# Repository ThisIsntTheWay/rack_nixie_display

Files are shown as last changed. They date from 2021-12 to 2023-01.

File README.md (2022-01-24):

# Project overview
1U rack mounted nixie display with IN-4 and INS-1 tubes.  
Uses an ESP32 and, optionally, a temperature sensor (such as the TMP36).  

## Description
The display, on its own, cannot actually do anything.  
It is designed to be used in tandem with its extensive REST API that allows complete control over the display:
* Controlling each individual tube (IN-4 & INS-1).
  * Both digits and brightness.
* Controlling the tube LEDs (red) *(not individually, as of PCB REV1)*.
* Controlling the onboard LED (blue).
* Basic authentication mechanism to ensure only select devices can talk to the display.
 
### Preview
Here is REV1 of a fully assembled unit mounted in a rack.  


### Hardware
This project uses the following components:
* 6x `TLP627`
* 4x `IN-4`
* 4x `SN74141 (or clones)`
* 2x `INS-1`
* 1x `TMP36`
* 1x `ESP32`
* 1x `LDO 3.3V regulator`

*Exclusively SMD components are used where applicable.  
HV devices/traces use THT instead, as clearances and creepage distances would be violated otherwise.*

#### Power
The device runs on 5V **max** and gets fed using an onboard micro-USB socket.  
Additionally, it can be *fully* turned off using a dedicated slide switch.

The 170V regulator has been sourced externally and is not included in the component list.  
Virtually any regulator works, as long as it has similar dimensions to the popular `NCH8200HV`.

#### Notes
To save on vertical space (to stay within the 1U mounting constraint), the BCD-Decoders and opto-isolators reside on *extension boards*.  
These are connected using standard 2.54mm headers.  

It is recommended to mount them using *straight* 2.54mm headers, just to reduce the risk of accidential shocks.

#### Documentation
Please refer to the [wiki](https://github.com/ThisIsntTheWay/rack_nixie_display/wiki) for documentation.

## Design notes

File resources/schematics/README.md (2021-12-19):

# Schematics
This is the cozy, comfy folder for all my schematics.

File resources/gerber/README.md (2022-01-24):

# Gerber repository
This is where all the gerber files reside.

### Main board, rev 1
  

### Main board, rev 2
  
* Increased IN-4 hole diameter (to ~5.5mm).
* Added INS-1 mounting holes.
* Added left-hand rackmount adapter mounting holes. 
---

### Extension board, rev 1


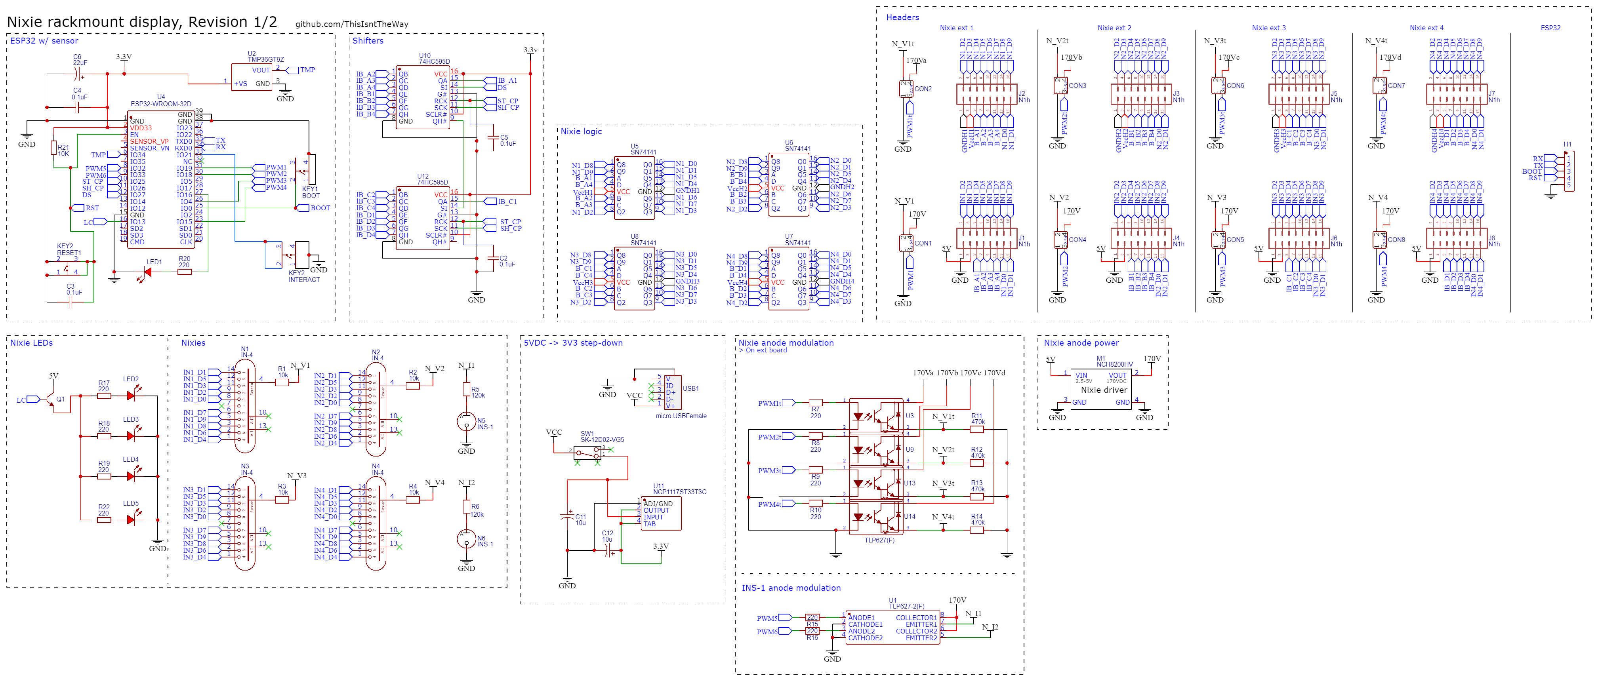
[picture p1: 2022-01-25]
resources/schematics/Schematic_rack_nixie_display_REV1-2.png

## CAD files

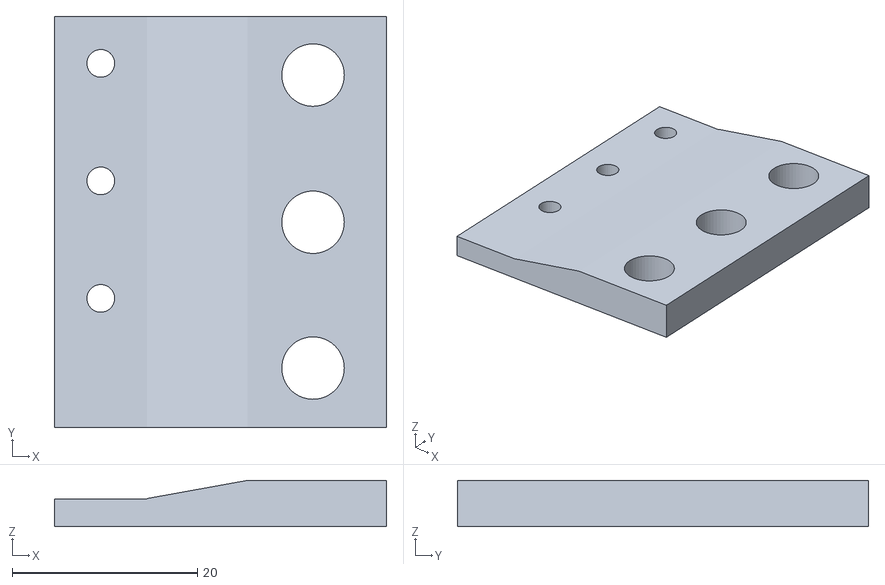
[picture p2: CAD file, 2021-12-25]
resources/3d_print/1U_rackmount_adapter.stl
35.9 x 44.5 x 5.00

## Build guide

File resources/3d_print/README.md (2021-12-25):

# 1U rackmount adapter
Quick and dirty rackmount adapter designed for REV1 of the nixie display PCB.  

## Dimensions
- **Length**: 35.9 mm
- **Height**: 44.5 mm  
- **Rackmount hole dm**: 6mm (M6)
- **PCB mounting hole dm**: 3mm (M3)

## Preview
STL preview

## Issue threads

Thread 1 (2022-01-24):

Temperatue not calculated properly

ThisIsntTheWay, 2022-01-24:
Using an ADC reading of 758, the ESP calculates the temperature to be ~202 °C.

ThisIsntTheWay, 2022-01-25:
Fixed in commit 2d5cd6435e7f5245d4c57619ec9423deb179b2f3.

Closed 2022-01-25.

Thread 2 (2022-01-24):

Tube PWM gets set to 0 if not specified in POST /api/display

ThisIsntTheWay, 2022-01-24:
In the request body, if the `tubes` array does not contain a PWM value for a corresponding tube, the PWM will be set to 0.

This is probably due to this code:
```C++
// websrv.cpp
int tubeIndex = atol(tube.key().c_str());
int tubePWM = tube.value()["pwm"].as<int>(); // <-- gets interpreted as 0 if missing/is NULL.
```

ToDo:
Check if argument PWM is present.

ThisIsntTheWay, 2022-01-24:
Fixed in commit 527de53.

Closed 2022-01-24.

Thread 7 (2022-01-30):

/api/tubes: If PWM is == 0, VAL gets set 0 instead.

ThisIsntTheWay, 2022-01-30:
Error possibly in `websrv.cpp`.

ThisIsntTheWay, 2022-01-30:
Update: `val` got set to 0 anyway if the `val` property was not present in the request body.
The fact that `pwm` does not get to 0 at all is another issue.

`val` now gets set correctly: 3684ca0

ThisIsntTheWay, 2022-01-30:
Fix superseded with commit 22e1b25.

Closed 2022-01-30.

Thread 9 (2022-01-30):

/api/display: PWM == 0 is not set in displayController.

ThisIsntTheWay, 2022-01-30:
If the request body sets `pwm` to 0, it is not actually updated in the `displayController.tubes` array.

Suspected code in `websrv.cpp`:
```C
if (tube.value()["pwm"]) {
    // ...
}
```

`0` at this point also represents a logical `false`, thus not satisfying this condition.
An alternate check if this property is present should be implemented.

ThisIsntTheWay, 2022-01-30:
Fixed in commit 22e1b25.

Closed 2022-01-30.

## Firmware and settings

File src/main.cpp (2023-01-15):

#include <Arduino.h>
#include <displayController.h>
#include <websrv.h>
#include <terminalAux.h>
#include <timekeeper.h>
#include <LITTLEFS.h>
#include <networkConfig.h>
#include <EEPROM.h>

/* -----------------------
            VARS
   ----------------------- */
#define EEPROM_REGION         256
#define INTERACT_BUTTON_PIN   21
#define RESET_DELAY_MS        5000
#define BAUD_RATE             115200

TaskHandle_t taskDisplay;
TaskHandle_t taskIndicator;
TaskHandle_t taskOLed;
TaskHandle_t taskTLed;
TaskHandle_t taskTime;

bool buttonState = true;
bool buttonIsBeingPressed = false;
 
/* -----------------------
            MAIN
   ----------------------- */

void setup() {
  Serial.begin(BAUD_RATE);

  DisplayController dController;
  xTaskCreate(taskSetStatusLED, "O_LED daemon", 4000, NULL, 4, &taskOLed);
  dController.OnboardLEDmode = 3;

  // EEPROM must be initialized before LittleFS, otherwise it will fail.
  EEPROM.begin(EEPROM_REGION);

  if (!LITTLEFS.begin()) {
    Serial.println("[X] FS mount failure!");
  }
  
  // Network stuff
  NetworkConfig nConfig;
  nConfig.InitConnection();
  webServerInit();
  
  // Remaining tasks
  xTaskCreate(taskSetDisplay, "Display daemon", 6500, NULL, 5, &taskDisplay);
  xTaskCreate(taskSetIndicators, "Indicator daemon", 6500, NULL, 4, &taskIndicator);
  xTaskCreate(taskSetLeds, "T_LED daemon", 4000, NULL, 4, &taskTLed);
  xTaskCreate(taskTimekeeper, "Time daemon", 4000, NULL, 3, &taskTime);
  dController.OnboardLEDmode = 0;

  // Interact button
  pinMode(INTERACT_BUTTON_PIN, INPUT_PULLUP);

  Serial.print(vt_green); Serial.println("System ready.");
  Serial.print(vt_default_colour);
}

void loop() {
  // Factory reset watchdog
  unsigned long currentMillis = millis();
  static unsigned long previousMillis = 0L;

  buttonState = digitalRead(INTERACT_BUTTON_PIN);
  if (!buttonState) {
    if (!buttonIsBeingPressed) {
      buttonIsBeingPressed = true;

      previousMillis = millis();
    } else {
      // Watch how long the button was pressed for.
      if (currentMillis - previousMillis >= RESET_DELAY_MS) {
        Serial.println(F("[!] System is being reset..."));
        vTaskDelete(taskDisplay);
        vTaskDelete(taskIndicator);
        vTaskDelete(taskOLed);
        vTaskDelete(taskTLed);
        vTaskDelete(taskTime);

        // Blank nixies, dim board LEDs
        Nixies n; n.BlankDisplay();
        ledcWrite(ONBOARD_LEDC_CHANNEL, 50);
        ledcWrite(TUBE_LEDC_CHANNEL, 50);

        LITTLEFS.end();
        if (LITTLEFS.format()) {
          Serial.println(F(" > Formatting complete."));
        } else {
          Serial.println(F(" > Could not format."));
        }

        // Destroy EEPROM
        Serial.printf(" > Formatting %d bytes of EEPROM...\n", EEPROM_REGION);
        for (int i = 0 ; i < EEPROM_REGION; i++) {
          EEPROM.write(i, 0);
        }

        EEPROM.commit();

        Serial.println(F(" > Rebooting..."));
        ESP.restart();
      }
    }
  } else {
    buttonIsBeingPressed = false;
  }
}

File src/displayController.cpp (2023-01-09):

#include <displayController.h>
#include <timekeeper.h>

/* -------------------
    Vars
   ------------------- */

Nixies nixies(DS_PIN, ST_PIN, SH_PIN);

int DisplayController::TubeVals[4][2] = {{9, 255}, {9, 255}, {9, 255}, {9, 255}};

bool DisplayController::Indicators[2] = {true, true};
bool DisplayController::AllowRESTcontrol = true;
bool DisplayController::Clock = false;

uint8_t DisplayController::LedPWM = 170;
uint8_t DisplayController::OnboardLedPWM = 75;
uint8_t DisplayController::OnboardLEDmode = 0;
uint8_t DisplayController::OnboardLEDblinkAmount = 0;

/* -------------------
    Main
   ------------------- */

void taskSetDisplay(void* parameter) {
    while (!nixies.IsReady()) {
        vTaskDelay(200);
    }

    Timekeeper timekeeper;
    int8_t lastSecond = 0;
    int8_t nowSecond = 0;

    for (;;) {
        int t[4] = {11, 11, 11, 11};

        if (!DisplayController::Clock) {
            // Normal operation
            for (int i = 0; i < 4; i++) {
                int8_t tubeVal = DisplayController::TubeVals[i][0];
                int8_t tubePWM = DisplayController::TubeVals[i][1];

                t[i] = tubeVal;

                // Fully turn off tube instead of leaving cathodes floating.
                if (tubeVal > 9)    { ledcWrite(i, 0); }
                else                { ledcWrite(i, tubePWM); }
            }
        } else {
        if (DisplayController::Clock) {
            // Native clock implementation
            DisplayController::Indicators[0] = false;

            DisplayController::TubeVals[0][0] = timekeeper.time.hours / 10;
            DisplayController::TubeVals[1][0] = timekeeper.time.hours % 10;
            DisplayController::TubeVals[2][0] = timekeeper.time.minutes / 10;
            DisplayController::TubeVals[3][0] = timekeeper.time.minutes % 10;

            // Invert indicator
            nowSecond = timekeeper.time.seconds;
            if (lastSecond != nowSecond) {
                DisplayController::Indicators[1] = !DisplayController::Indicators[1];
                lastSecond = nowSecond;
            }

            for (int i = 0; i < 4; i++) {
                int8_t tubePWM = DisplayController::TubeVals[i][1];
                ledcWrite(i, tubePWM);
            }
        }

        // Populate t[]
        for (int i = 0; i < 4; i++) {
            int8_t tubeVal = DisplayController::TubeVals[i][0];
            int8_t tubePWM = DisplayController::TubeVals[i][1];

            t[i] = tubeVal;

            // Fully turn off tube instead of leaving cathodes floating.
            if (tubeVal > 9)    { ledcWrite(i, 0); }
            else                { ledcWrite(i, tubePWM); }
        }
        
        // Blank all tubes that were not considered. (Their index is missing in TubeVals)
        for (int i = 0; i < 4; i++) {
            if (t[i] == 11) {
                ledcWrite(i, 0);
            }
        }

        nixies.SetDisplay(t);
        vTaskDelay(TASK_TICK_DELAY);
    }
}

void taskSetIndicators(void* parameter) {
    while (!nixies.IsReady()) {
        vTaskDelay(200);
    }

    for (;;) {
        for (int i = 0; i < 2; i++) {
            nixies.SetIndicator(i, DisplayController::Indicators[i]);
        }

        vTaskDelay(TASK_TICK_DELAY);
    }
}

// Tube LEDs
void taskSetLeds(void* parameter) {
    pinMode(TUBE_LED_PIN, OUTPUT);

    ledcSetup(TUBE_LEDC_CHANNEL, LEDC_PWM_FREQUENCY, 8);
    ledcAttachPin(TUBE_LED_PIN, TUBE_LEDC_CHANNEL);

    for (;;) {
        ledcWrite(TUBE_LEDC_CHANNEL, DisplayController::LedPWM);

        vTaskDelay(TASK_TICK_DELAY);
    }
}

// Status LED for ESP32
void taskSetStatusLED(void* parameter) {
    pinMode(ONBOARD_LED_PIN, OUTPUT);

    ledcSetup(ONBOARD_LEDC_CHANNEL, LEDC_PWM_FREQUENCY, 8);
    ledcAttachPin(ONBOARD_LED_PIN, ONBOARD_LEDC_CHANNEL);

    for (;;) {
        switch (DisplayController::OnboardLEDmode) {
            case 1:
                // Blink
                // -> LED is turned OFF but turns ON in a blinking matter
                for (int i = 0; i <= DisplayController::OnboardLEDblinkAmount; i++) {
                    ledcWrite(ONBOARD_LEDC_CHANNEL, DisplayController::OnboardLedPWM);
                    vTaskDelay(ONBOARD_LED_BLINK_INTERVAL);
                    ledcWrite(ONBOARD_LEDC_CHANNEL, 0);
                    vTaskDelay(ONBOARD_LED_BLINK_INTERVAL);
                }

                vTaskDelay(1000);
                break;
            case 2:
                // "Inverted" blink
                // -> LED is turned ON but turns OFF in a blinking matter
                ledcWrite(ONBOARD_LEDC_CHANNEL, DisplayController::OnboardLedPWM);
                for (int i = 0; i <= DisplayController::OnboardLEDblinkAmount; i++) {
                    ledcWrite(ONBOARD_LEDC_CHANNEL, 0);
                    vTaskDelay(ONBOARD_LED_BLINK_INTERVAL);
                    ledcWrite(ONBOARD_LEDC_CHANNEL, DisplayController::OnboardLedPWM);
                    vTaskDelay(ONBOARD_LED_BLINK_INTERVAL);
                }

                vTaskDelay(1000);
                break;
            case 3: {
                // Pulsate
                // Duty cycles above 150 are hardly perceived as brighter, so this value serves as the ceiling.
                uint8_t maxPWM = 150;
                for (int i = 0; i < maxPWM; i++) {
                    if (DisplayController::OnboardLEDmode != 3) break;

                    ledcWrite(ONBOARD_LEDC_CHANNEL, i);
                    vTaskDelay(ONBOARD_LED_PULSE_INTERVAL);
                }
                for (int i = 170; i > 0; i--) {
                    if (DisplayController::OnboardLEDmode != 3) break;

                    ledcWrite(ONBOARD_LEDC_CHANNEL, i);
                    vTaskDelay(ONBOARD_LED_PULSE_INTERVAL);
                }
                break;
            }
            default:
                // Light up using specified PWM, a.k.a mode "0".
                ledcWrite(ONBOARD_LEDC_CHANNEL, DisplayController::OnboardLedPWM);
                break;
        }

        vTaskDelay(TASK_TICK_DELAY);
    }
}

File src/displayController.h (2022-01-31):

#ifndef DISPLAYCONTROL_H
#define DISPLAYCONTROL_H

#define TUBE_LED_PIN 13
#define ONBOARD_LED_PIN 16
#define DS_PIN  27   // Data
#define SH_PIN  26   // Clock
#define ST_PIN  25   // Latch

#define TASK_TICK_DELAY 100
#define LEDC_PWM_FREQUENCY 100
#define TUBE_LEDC_CHANNEL 14
#define ONBOARD_LEDC_CHANNEL 15

#define ONBOARD_LED_BLINK_INTERVAL 200
#define ONBOARD_LED_PULSE_INTERVAL 5

#include <Arduino.h>
#include <nixies.h>

class DisplayController {
    public:
        static int TubeVals[4][2];
        static bool Indicators[2];
        static uint8_t LedPWM;
        static uint8_t OnboardLedPWM;
        static uint8_t OnboardLEDmode;
        static uint8_t OnboardLEDblinkAmount;
        static bool AllowRESTcontrol;
        static bool Clock;
};

void taskSetDisplay(void* parameter);
void taskSetIndicators(void* parameter);
void taskSetStatusLED(void* parameter);
void taskSetLeds(void* parameter);

#endif

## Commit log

2021-12-12 Add lib deps and partition table
    [partition_table.csv]
2021-12-25 Add 3D printed 1U rackmount adapter
    [1U_rackmount_adapter.stl]
2021-12-30 Correct opto pins, add isReady() method,
    [nixies.cpp]
2021-12-30 [Broken] Create displayController, move arrays there and downgrade ledVals to just int
    [displayController.cpp, displayController.h]
2021-12-30 Fix nixies invocation and define shift register pins
    [displayController.cpp, displayController.h]
2021-12-30 Fix redefinition errors due to recursion errors
    Achieved by moving the three offending variables into a static class and changing all references to them accordingly.
    [displayController.cpp, displayController.h]
2021-12-31 Fix terminal baud, add colors and actually start webserver.
    [main.cpp]
2021-12-31 Overhaul taskSetDisplay
    Will now turn off tubes with floating cathodes, i.e. their BCD decoders have received >9.
    This now also handles the unsorted tubeVals[] array.
    A performance gain could be achieved by simply sorting the thing properly.
2021-12-31 Add functionality to alter onboard LED behavior.
2021-12-31 Add REV2 of PCB
2021-12-31 Update PCB REV2 resources
2021-12-31 Fix tube parameter behaviour, add some DEBUG #ifdef
2022-01-23 Fix incorrect tube order
    [nixies.cpp]
2022-01-23 Fix INS-1 and LEDC logic for PCB LEDs.
    LEDC channel exceeded max. of 16 and LED pins were not declared as outputs.
    Additionally, Nixies::setIndicator did not use ledcWrite.
    [displayController.cpp, displayController.h, nixies.cpp]
2022-01-23 Rename *tubeHandler
2022-01-23 Fix LEDC channel definitions, add O_LED blink interval, add additional O_LED mode.
    O_LED now blinks less aggressively, pulsates for a shorter time and now has an "inverted blink".
    [displayController.cpp, displayController.h]
2022-01-23 Fix variable declaration in switch..case statement
    [displayController.cpp]
2022-01-23 Return time info even if FS was not mounted, WIP network handler
2022-01-23 Add warning on FS mount failure.
2022-01-23 Mount FS in main() and init network using NetworkConfig.
2022-01-24 Fix tubePWM updating despite it not being defined in request.
    Also add better error handling.
2022-01-24 Start O_LED task at beginning, only change onboard LED mode once bootup is done.
2022-01-24 Set hostname for device.
2022-01-24 Add landing page.
2022-01-24 Add <title> to landing page.
2022-01-25 Update schematic.
2022-01-25 Fix array starting too early.
    [nixies.cpp]
2022-01-25 Add factory reset by button.
    For now, this logic resides in loop()
    [main.cpp]
2022-01-25 Fix pulsating mode not really pulsating.
    [displayController.cpp]
2022-01-25 Create specific API endpoints, fix temperature readout
2022-01-26 Fix Authenticator() and EEPROM format procedure.
    [main.cpp]
2022-01-26 Update Clock.ps1
    No longer toggle indicator based on result of a GET request.
    This saves a few milliseconds.
2022-01-27 Add native clock implementation, add status[] to /api/display
    Also decreases initial PWM value for onboard LEDs.
2022-01-27 Decrease complexity of TubeVals[,]
    The array is ordered anyway, so the "tubeIndex" at position 0 is no longer required.
    [displayController.cpp, displayController.h]
2022-01-30 Only update tubeVal if property is present.
2022-01-30 Actually fix tubeVa & tubePWM not updating properly.
2022-01-31 Ensure pascal-case conformity, add WiFi status info.
2022-02-19 Increase /api/display/tubes JSON mem buffer.
2022-02-20 Change operation of clock mode.
    Clock mode now alters the tubeVals[] variable instead of bypassing it.
    This makes it possible to now see the clock tube values in /api/display.
2023-03-10 Fix PWM body
